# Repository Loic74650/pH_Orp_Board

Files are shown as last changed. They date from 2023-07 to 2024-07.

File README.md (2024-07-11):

# pH_Orp_Board
## A 16 bits, two-channels, analog to digital convertion board with galavnic isolation to measure pH and Orp levels in pools and similar environments

This project is based on the original project from Roberto Buti: https://github.com/reef-pi/pH-Board.<br />
This modified version features a double input for simultaneous pH and Orp measurements on the same board, based on the ADS1115 IC.<br />
This board is an ideal companion to the PoolMaster project: https://github.com/Loic74650/PoolMaster.<br />
The 5Volts power supply to this board should be low noise and low drift (sorry no spec).<br /><br />
A alternative (and likely better) routing of the board was performed by @Gixy31 and is available here: https://github.com/Gixy31/ESP32-PoolMaster/tree/main/pH_Orp%20Board%20V2

<br />
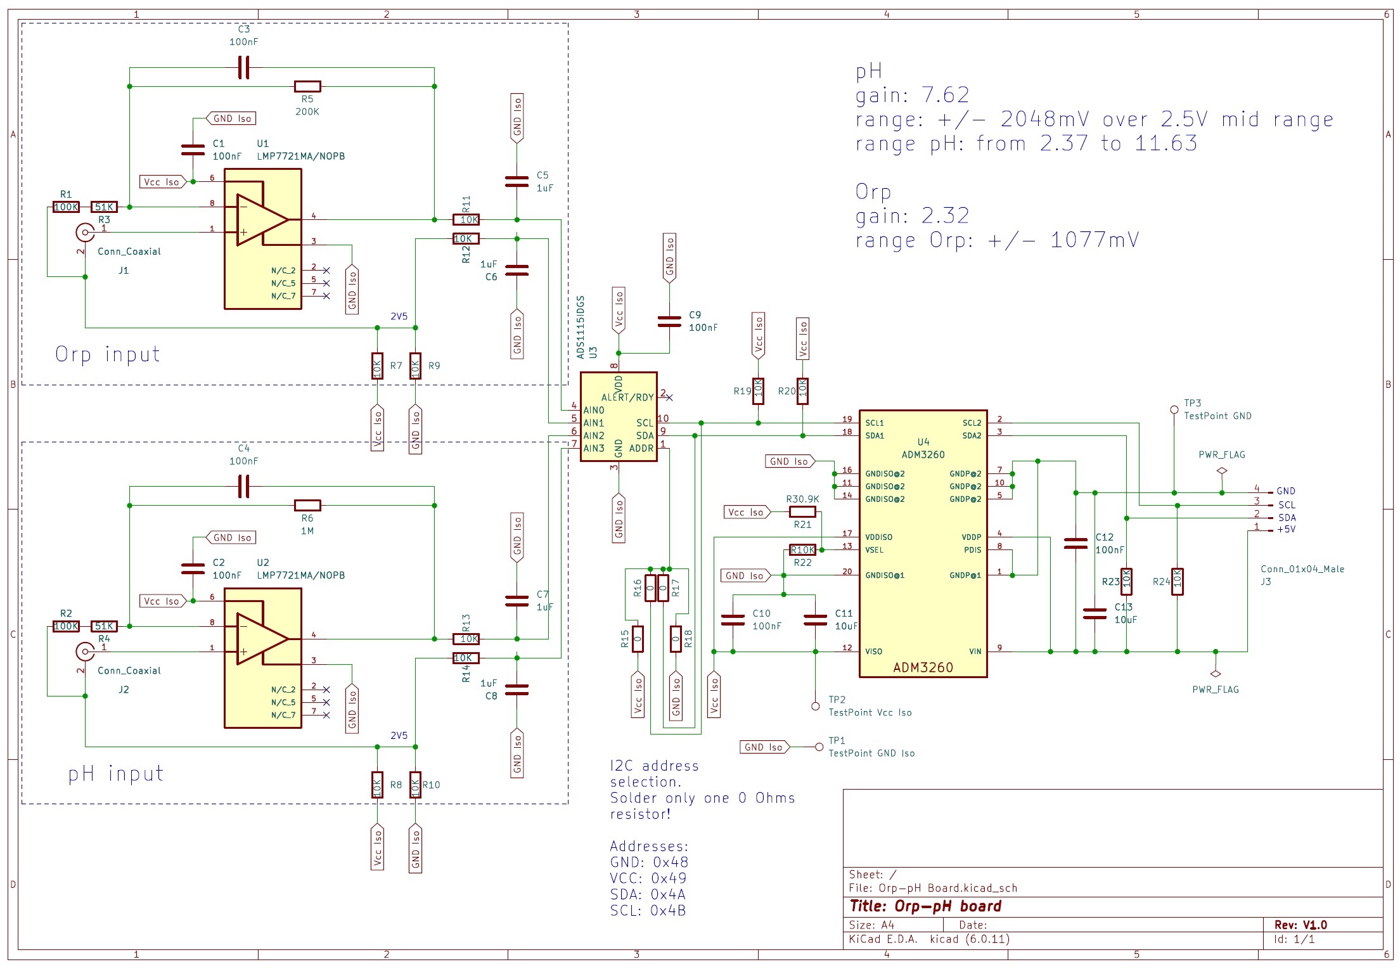
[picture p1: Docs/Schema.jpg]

Schematics <br /><br />

<br />
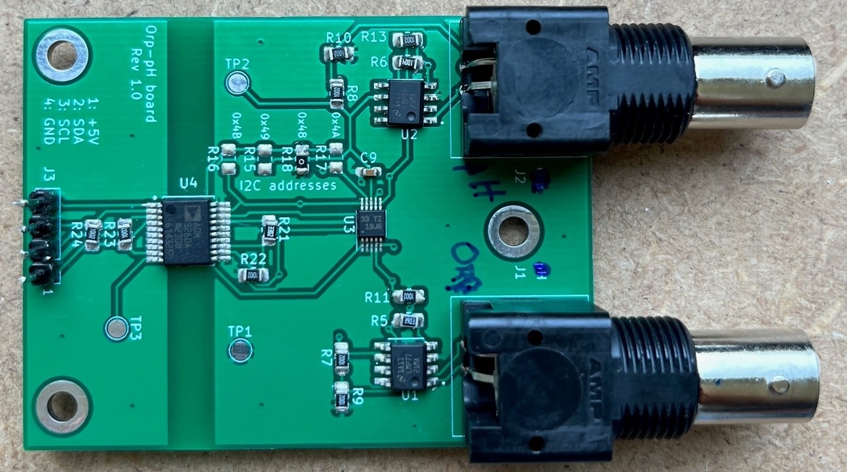
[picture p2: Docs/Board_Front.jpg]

PCB front <br /><br />

<br />
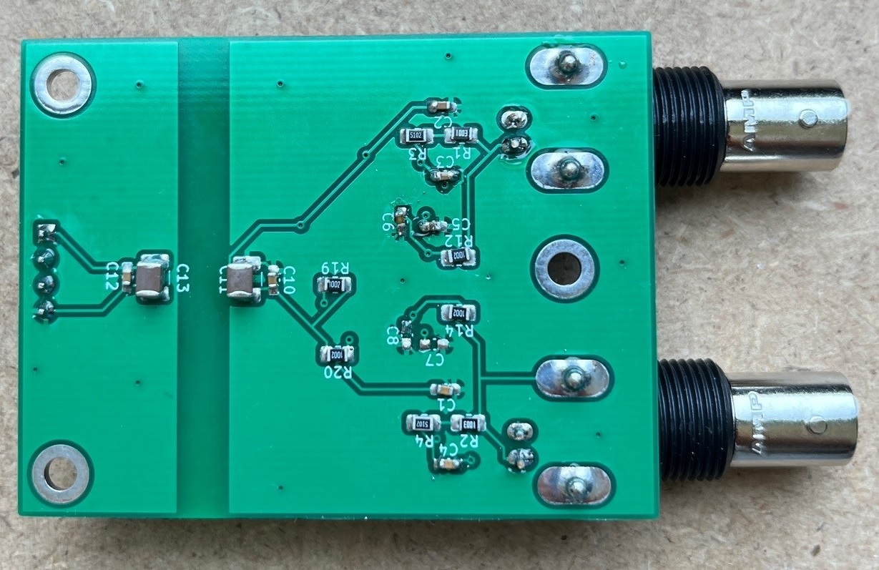
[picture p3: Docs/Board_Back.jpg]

PCB back <br /><br />

<br />
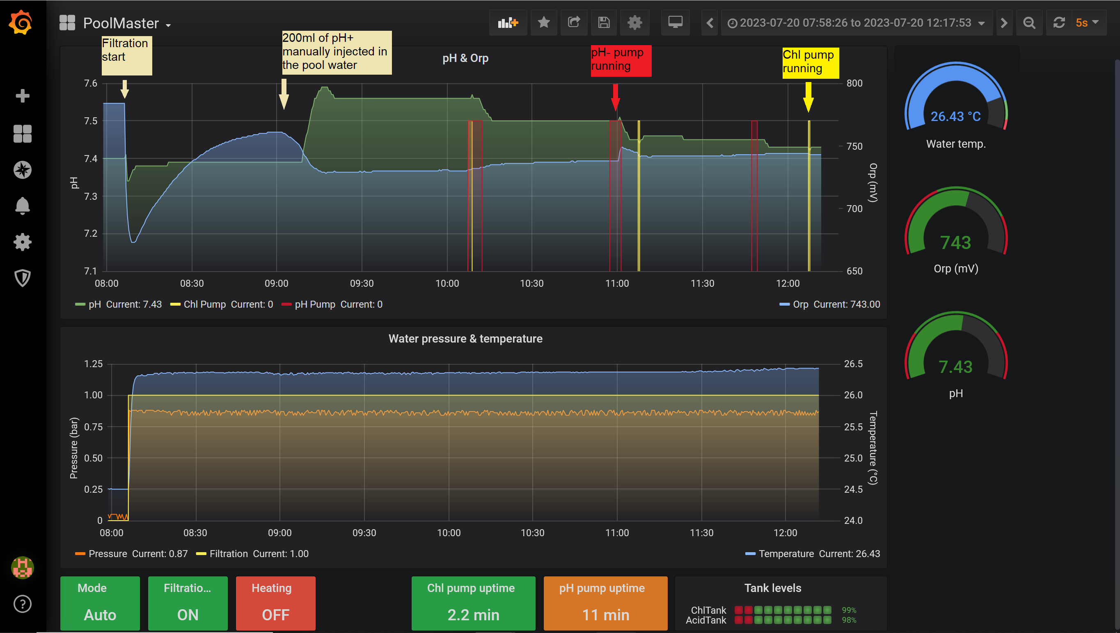
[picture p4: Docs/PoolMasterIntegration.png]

PoolMaster dashboard with pH_Orp_Board integrated<br /><br />

<br />
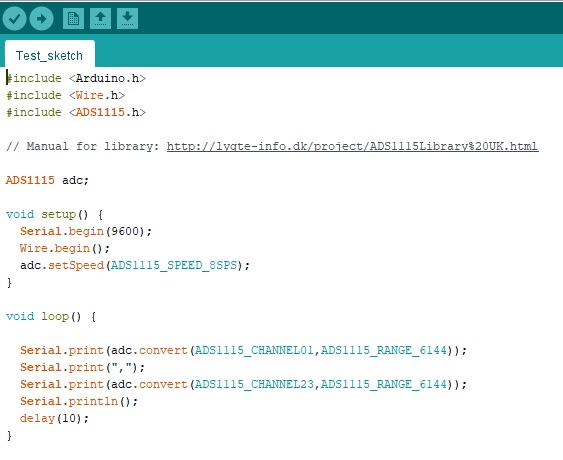
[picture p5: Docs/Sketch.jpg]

Basic sketch provided in this repository to test the PCB with this library: <br /><br />
https://lygte-info.dk/project/ADS1115Library%20UK.html<br /><br />

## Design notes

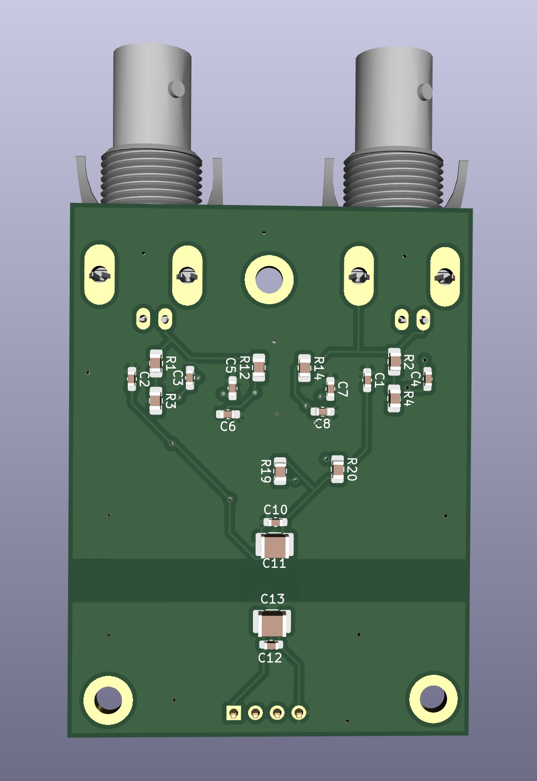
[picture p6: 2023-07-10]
Docs/PCB_Bottom.jpg

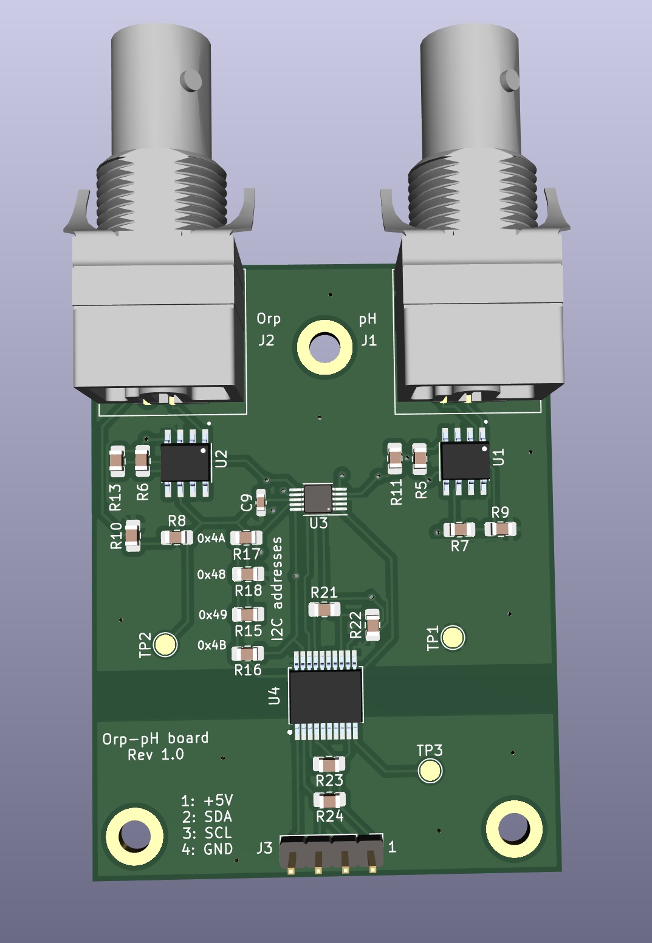
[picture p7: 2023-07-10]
Docs/PCB_Top.jpg

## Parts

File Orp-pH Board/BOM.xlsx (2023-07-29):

Column1 | Column2 | Column3 | Column4 | Column5 | Column6 | Column7 | Column8 | Column9
Source: | C:\Users\USER\Documents\GitHub\pH-Board\Kicad\Orp-pH Board\Orp-pH Board.kicad_sch
Date: | 25/05/2023 13:23:16
Tool: | Eeschema (6.0.11)
Generator: | C:\Program Files\KiCad\6.0\bin\scripting\plugins/bom_csv_grouped_by_value_with_fp.py
Component Count: | 47
Ref | Qnty | Value | Cmp name | Footprint | Description | Vendor | Unit Price HT€ | Total Price HT€
C1, C2, C3, C4, C9, C10, C12, | 7 | 100nF | C | Capacitor_SMD:C_0603_1608Metric_Pad1.08x0.95mm_HandSolder | Unpolarized capacitor |  |  | 0
C5, C6, C7, C8, | 4 | 1uF | C | Capacitor_SMD:C_0603_1608Metric_Pad1.08x0.95mm_HandSolder | Unpolarized capacitor |  |  | 0
C11, C13, | 2 | 10uF | C | Capacitor_SMD:C_1210_3225Metric_Pad1.33x2.70mm_HandSolder | Unpolarized capacitor |  |  | 0
J1, J2, | 2 | Conn_Coaxial | Conn_Coaxial | Connector_Coaxial:BNC_Amphenol_B6252HB-NPP3G-50_Horizontal | coaxial connector (BNC, SMA, SMB, SMC, Cinch/RCA, LEMO, ...) | https://www.mouser.fr/ProductDetail/TE-Connectivity-AMP/227161-9?qs=ZKw1f99oBB2J9LYPbCoP6Q%3D%3D | 6.06 | 12.12
J3, | 1 | Conn_01x04_Male | Conn_01x04_Male | Connector_PinHeader_2.54mm:PinHeader_1x04_P2.54mm_Vertical | Generic connector, single row, 01x04, script generated (kicad-library-utils/schlib/autogen/connector/) |  |  | 0
R1, R2, | 2 | 100K | R | Capacitor_SMD:C_0805_2012Metric_Pad1.18x1.45mm_HandSolder | Resistor |  |  | 0
R3, R4, | 2 | 51K | R | Capacitor_SMD:C_0805_2012Metric_Pad1.18x1.45mm_HandSolder | Resistor |  |  | 0
R5, | 1 | 200K | R | Capacitor_SMD:C_0805_2012Metric_Pad1.18x1.45mm_HandSolder | Resistor |  |  | 0
R6, | 1 | 1M | R | Capacitor_SMD:C_0805_2012Metric_Pad1.18x1.45mm_HandSolder | Resistor |  |  | 0
R7, R8, R9, R10, R11, R12, R13, R14, R19, R20, R23, R24, | 12 | 10K | R | Capacitor_SMD:C_0805_2012Metric_Pad1.18x1.45mm_HandSolder | Resistor |  |  | 0
R15, R16, R17, R18, | 4 | 0 | R | Capacitor_SMD:C_0805_2012Metric_Pad1.18x1.45mm_HandSolder | Resistor |  |  | 0
R21, | 1 | R30.9K | R | Capacitor_SMD:C_0805_2012Metric_Pad1.18x1.45mm_HandSolder | Resistor |  |  | 0
R22, | 1 | R10K | R | Capacitor_SMD:C_0805_2012Metric_Pad1.18x1.45mm_HandSolder | Resistor |  |  | 0
TP1, | 1 | TestPoint GND Iso | TestPoint | TestPoint:TestPoint_Pad_D2.0mm | test point |  |  | 0
TP2, | 1 | TestPoint Vcc Iso | TestPoint | TestPoint:TestPoint_Pad_D2.0mm | test point |  |  | 0
TP3, | 1 | TestPoint Vcc | TestPoint | TestPoint:TestPoint_Pad_D2.0mm | test point |  |  | 0
U1, U2, | 2 | LMP7721MA/NOPB | LMP7721MA{slash}NOPB | SOIC127P599X175-8N |  | https://www.ti.com/lit/ds/symlink/ads1115-q1.pdf?HQS=dis-mous-null-mousermode-dsf-pf-null-wwe&ts=1685176951071 | 5.68 | 11.36
U3, | 1 | ADS1115IDGS | ADS1115IDGS | Package_SO:TSSOP-10_3x3mm_P0.5mm | Ultra-Small, Low-Power, I2C-Compatible, 860-SPS, 16-Bit ADCs With Internal Reference, Oscillator, and Programmable Comparator, VSSOP-10 |  | 6.26 | 6.26
U4, | 1 | ADM3260 | ADM3260 | ADM3260:SOP65P780X200-20N |  |  | 10.2 | 10.2
 |  |  |  |  |  |  | TOTAL HT€ | 39.94

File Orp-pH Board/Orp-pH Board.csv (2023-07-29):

Source: | C:\Users\USER\Documents\GitHub\pH-Board\Kicad\Orp-pH Board\Orp-pH Board.kicad_sch
Date: | 25/05/2023 13:23:16
Tool: | Eeschema (6.0.11)
Generator: | C:\Program Files\KiCad\6.0\bin\scripting\plugins/bom_csv_grouped_by_value_with_fp.py
Component Count: | 47
Ref | Qnty | Value | Cmp name | Footprint | Description | Vendor
C1, C2, C3, C4, C9, C10, C12, | 7 | 100nF | C | Capacitor_SMD:C_0603_1608Metric_Pad1.08x0.95mm_HandSolder | Unpolarized capacitor
C5, C6, C7, C8, | 4 | 1uF | C | Capacitor_SMD:C_0603_1608Metric_Pad1.08x0.95mm_HandSolder | Unpolarized capacitor
C11, C13, | 2 | 10uF | C | Capacitor_SMD:C_1210_3225Metric_Pad1.33x2.70mm_HandSolder | Unpolarized capacitor
J1, J2, | 2 | Conn_Coaxial | Conn_Coaxial | Connector_Coaxial:BNC_Amphenol_B6252HB-NPP3G-50_Horizontal | coaxial connector (BNC, SMA, SMB, SMC, Cinch/RCA, LEMO, ...)
J3, | 1 | Conn_01x04_Male | Conn_01x04_Male | Connector_PinHeader_2.54mm:PinHeader_1x04_P2.54mm_Vertical | Generic connector, single row, 01x04, script generated (kicad-library-utils/schlib/autogen/connector/)
R1, R2, | 2 | 100K | R | Capacitor_SMD:C_0805_2012Metric_Pad1.18x1.45mm_HandSolder | Resistor
R3, R4, | 2 | 51K | R | Capacitor_SMD:C_0805_2012Metric_Pad1.18x1.45mm_HandSolder | Resistor
R5, | 1 | 200K | R | Capacitor_SMD:C_0805_2012Metric_Pad1.18x1.45mm_HandSolder | Resistor
R6, | 1 | 1M | R | Capacitor_SMD:C_0805_2012Metric_Pad1.18x1.45mm_HandSolder | Resistor
R7, R8, R9, R10, R11, R12, R13, R14, R19, R20, R23, R24, | 12 | 10K | R | Capacitor_SMD:C_0805_2012Metric_Pad1.18x1.45mm_HandSolder | Resistor
R15, R16, R17, R18, | 4 | 0 | R | Capacitor_SMD:C_0805_2012Metric_Pad1.18x1.45mm_HandSolder | Resistor
R21, | 1 | R30.9K | R | Capacitor_SMD:C_0805_2012Metric_Pad1.18x1.45mm_HandSolder | Resistor
R22, | 1 | R10K | R | Capacitor_SMD:C_0805_2012Metric_Pad1.18x1.45mm_HandSolder | Resistor
TP1, | 1 | TestPoint GND Iso | TestPoint | TestPoint:TestPoint_Pad_D2.0mm | test point
TP2, | 1 | TestPoint Vcc Iso | TestPoint | TestPoint:TestPoint_Pad_D2.0mm | test point
TP3, | 1 | TestPoint Vcc | TestPoint | TestPoint:TestPoint_Pad_D2.0mm | test point
U1, U2, | 2 | LMP7721MA/NOPB | LMP7721MA{slash}NOPB | SOIC127P599X175-8N
U3, | 1 | ADS1115IDGS | ADS1115IDGS | Package_SO:TSSOP-10_3x3mm_P0.5mm | Ultra-Small, Low-Power, I2C-Compatible, 860-SPS, 16-Bit ADCs With Internal Reference, Oscillator, and Programmable Comparator, VSSOP-10
U4, | 1 | ADM3260 | ADM3260 | ADM3260:SOP65P780X200-20N

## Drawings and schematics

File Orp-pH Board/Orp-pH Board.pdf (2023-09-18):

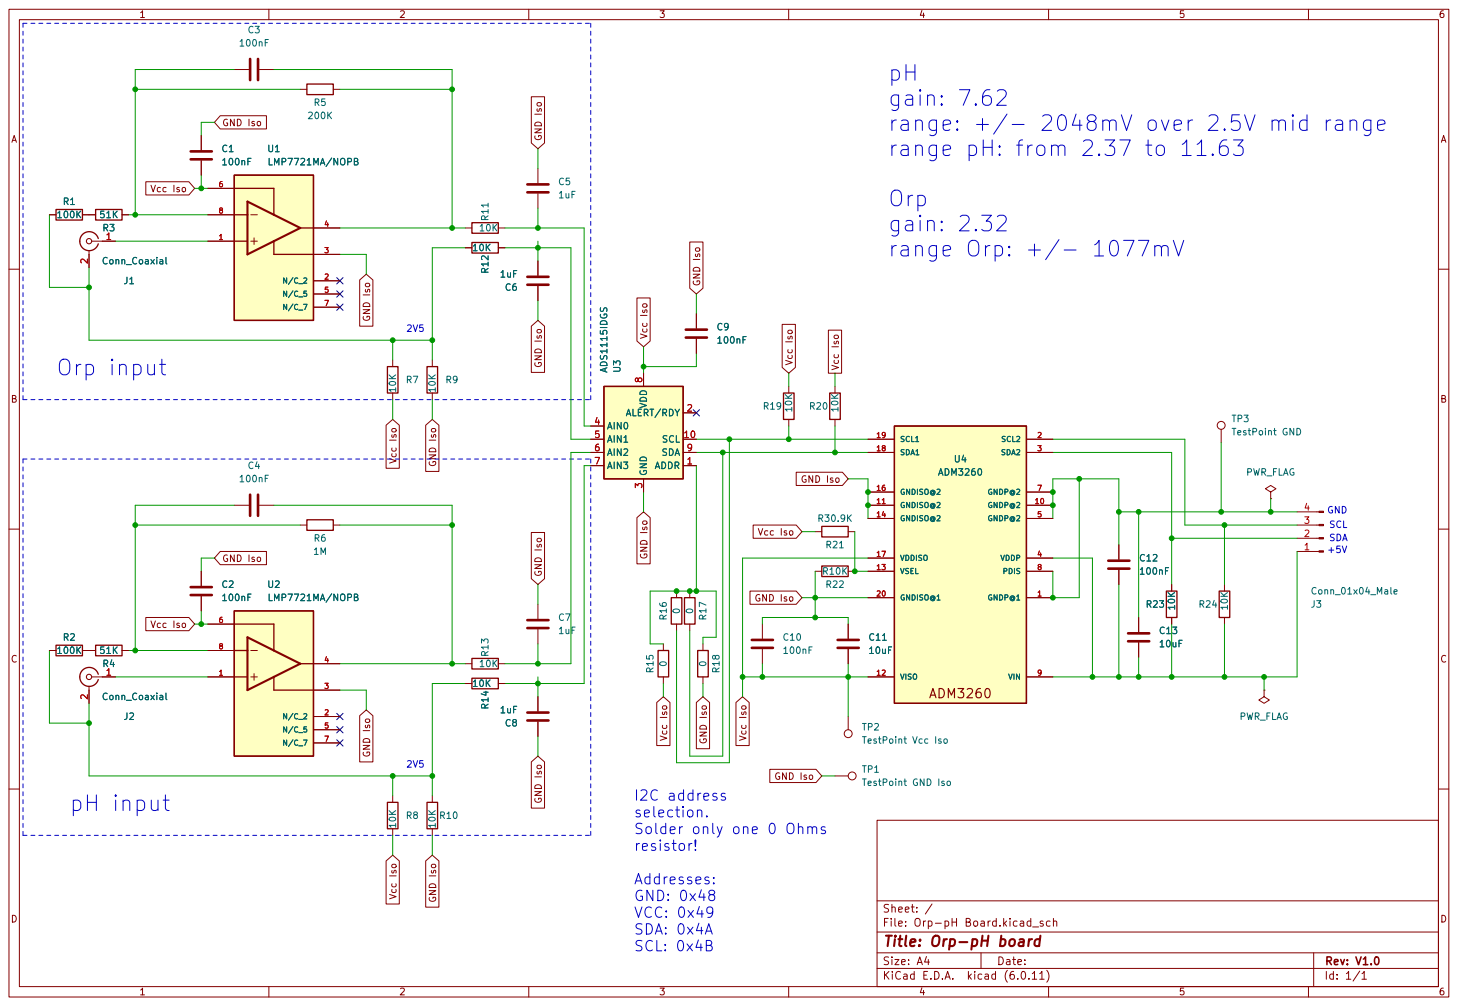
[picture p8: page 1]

gain: 7.62
range pH: from 2.37 to 11.63

selection.
Solder only one 0 Ohms
resistor!

Id: 1/1 Title: Orp-pH board

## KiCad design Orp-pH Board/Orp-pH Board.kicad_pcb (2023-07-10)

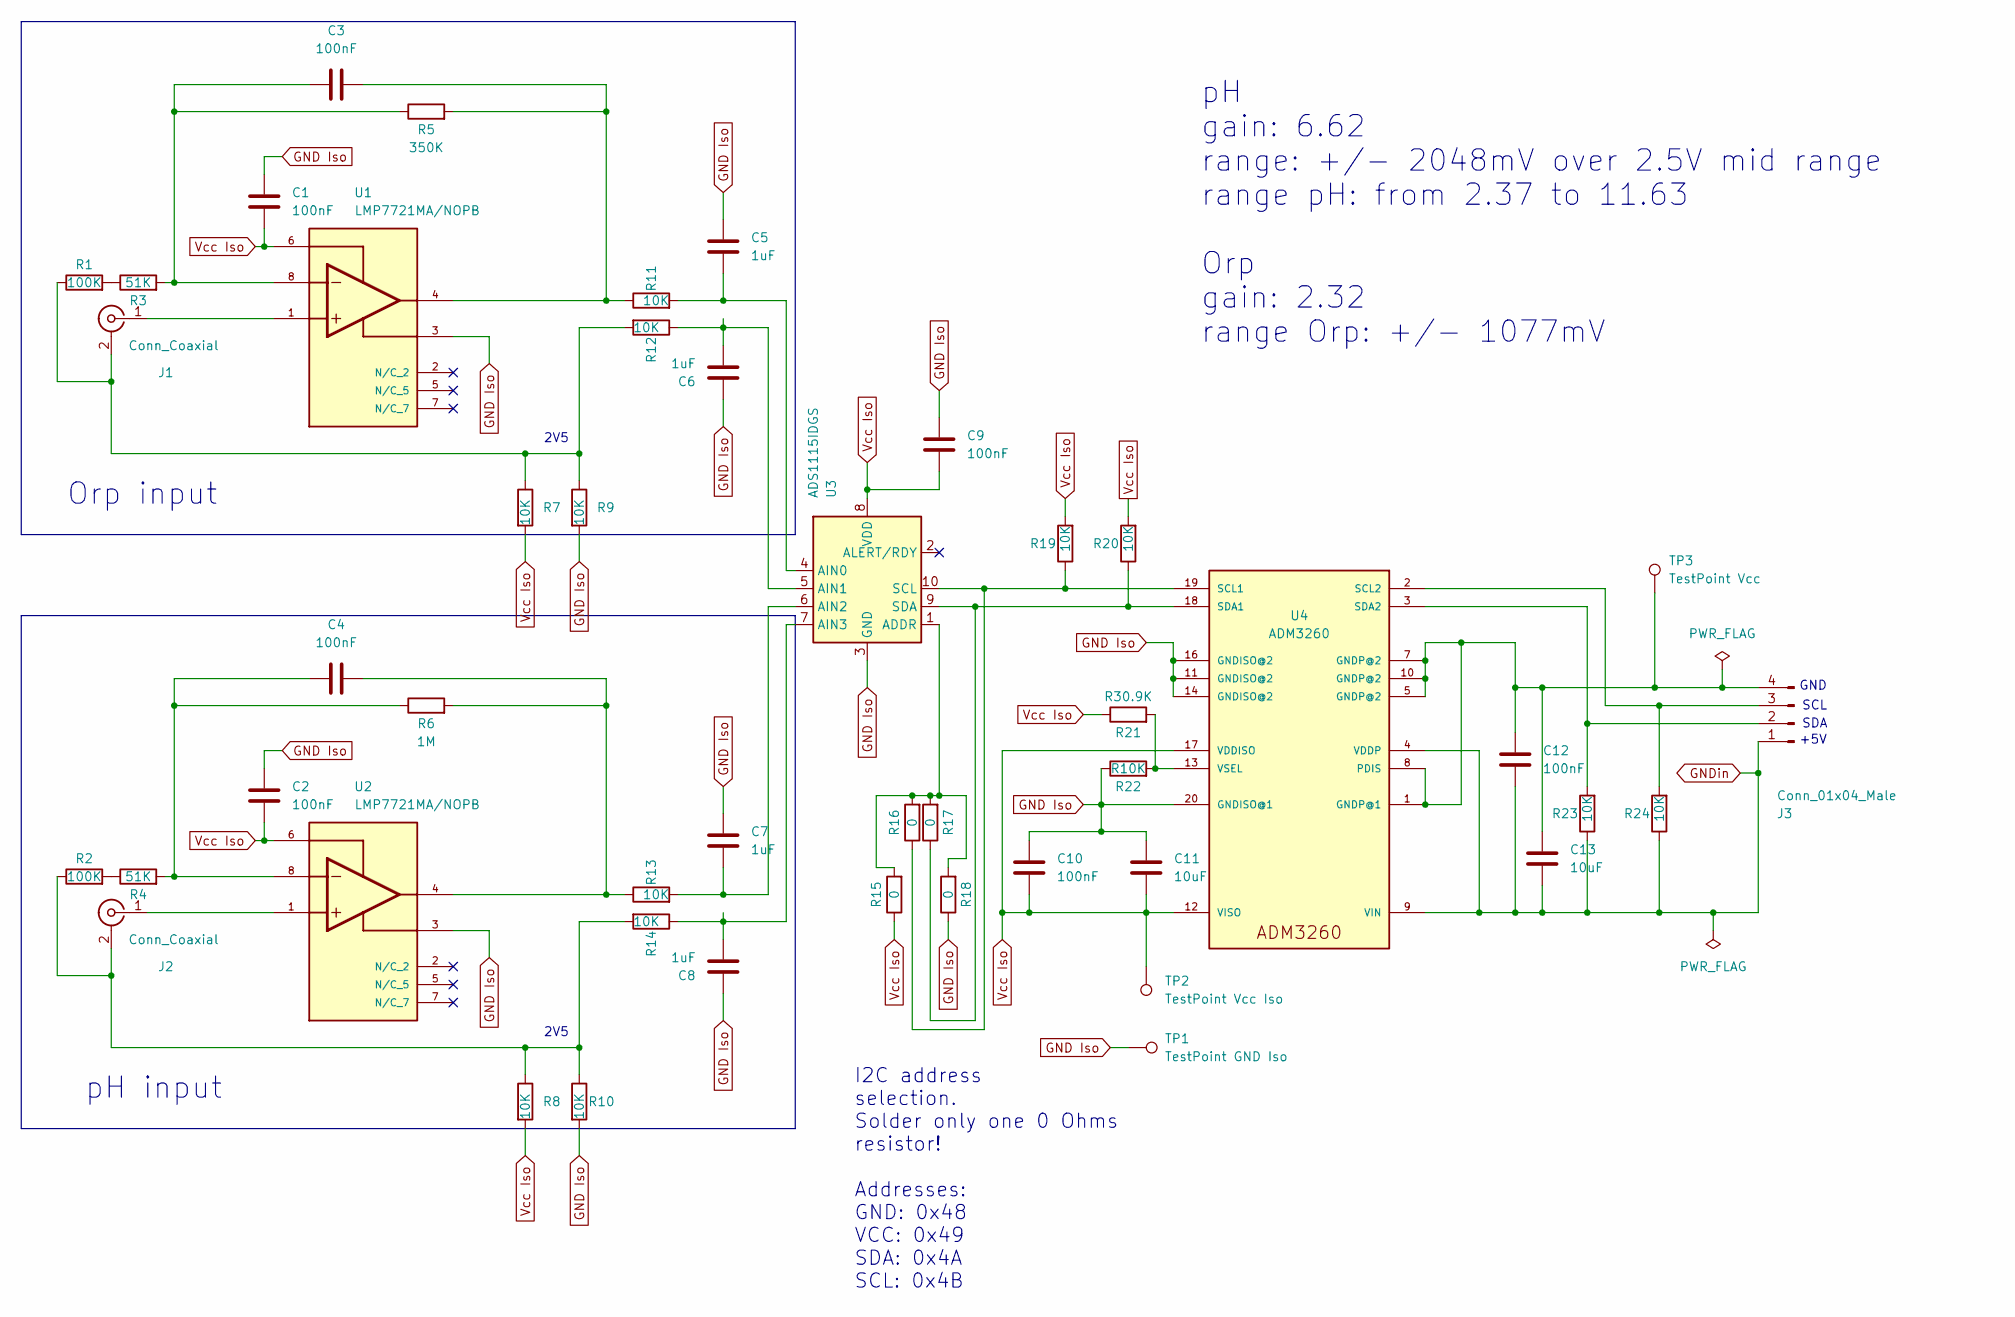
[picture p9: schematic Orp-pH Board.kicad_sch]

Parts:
C1, C2, C3, C4, C9, C10, C12: 100nF; C_0603_1608Metric_Pad1.08x0.95mm_HandSolder
C5, C6, C7, C8: 1uF; C_0603_1608Metric_Pad1.08x0.95mm_HandSolder
C11, C13: 10uF; C_1210_3225Metric_Pad1.33x2.70mm_HandSolder
J1, J2: Conn_Coaxial; BNC_Amphenol_B6252HB-NPP3G-50_Horizontal
J3: Conn_01x04_Male; PinHeader_1x04_P2.54mm_Vertical
R1, R2: 100K; C_0805_2012Metric_Pad1.18x1.45mm_HandSolder
R3, R4: 51K; C_0805_2012Metric_Pad1.18x1.45mm_HandSolder
R5: 350K; C_0805_2012Metric_Pad1.18x1.45mm_HandSolder
R6: 1M; C_0805_2012Metric_Pad1.18x1.45mm_HandSolder
R7, R8, R9, R10, R11, R12, R13, R14, R19, R20, R23, R24: 10K; C_0805_2012Metric_Pad1.18x1.45mm_HandSolder
R15, R16, R17, R18: 0; C_0805_2012Metric_Pad1.18x1.45mm_HandSolder
R21: R30.9K; C_0805_2012Metric_Pad1.18x1.45mm_HandSolder
R22: R10K; C_0805_2012Metric_Pad1.18x1.45mm_HandSolder
TP1: TestPoint GND Iso; TestPoint_Pad_D2.0mm
TP2: TestPoint Vcc Iso; TestPoint_Pad_D2.0mm
TP3: TestPoint Vcc; TestPoint_Pad_D2.0mm
U1, U2: LMP7721MA/NOPB; SOIC127P599X175-8N; PARTREV E
U3: ADS1115IDGS; VSSOP-10_3x3mm_P0.5mm
U4: ADM3260; SOP65P780X200-20N

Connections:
GND Iso: C1.1, C2.1, C5.1, C6.1, C7.1, C8.1, C9.1, C10.1, C11.1, R9.2, R10.2, R18.1, R22.1, TP1.1, U1.3, U2.3, U3.3 (GND), U4.11 (GNDISO@2), U4.14 (GNDISO@2), U4.16 (GNDISO@2), U4.20 (GNDISO@1)
unnamed: C3.1, R3.2, R5.1, U1.8
unnamed: C3.2, R5.2, R11.1, U1.4
unnamed: C4.1, R4.2, R6.1, U2.8
unnamed: C4.2, R6.2, R13.1, U2.4
unnamed: C5.2, R11.2, U3.4 (AIN0)
unnamed: C6.2, R12.1, U3.5 (AIN1)
unnamed: C7.2, R13.2, U3.6 (AIN2)
unnamed: C8.2, R14.1, U3.7 (AIN3)
unnamed: C12.2, C13.2, J3.1, R23.1, R24.1, U4.4 (VDDP), U4.9 (VIN)
unnamed: J1.1 (In), U1.1
unnamed: J1.2 (Ext), R1.1, R7.1, R9.1, R12.2
unnamed: J2.1 (In), U2.1
unnamed: J2.2 (Ext), R2.1, R8.1, R10.1, R14.2
unnamed: J3.2, R23.2, U4.3 (SDA2)
unnamed: J3.3, R24.2, U4.2 (SCL2)
unnamed: R1.2, R3.1
unnamed: R2.2, R4.1
unnamed: R15.2, R16.2, R17.2, R18.2, U3.1 (ADDR)
unnamed: R16.1, R19.1, U3.10 (SCL), U4.19 (SCL1)
unnamed: R17.1, R20.1, U3.9 (SDA), U4.18 (SDA1)
unnamed: R21.2, R22.2, U4.13 (VSEL)
Vcc Iso: C1.2, C2.2, C9.2, C10.2, C11.2, R7.2, R8.2, R15.1, R19.2, R20.2, R21.1, TP2.1, U1.6, U2.6, U3.8 (VDD), U4.12 (VISO), U4.17 (VDDISO)

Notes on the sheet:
+5V
GND
Orp input
SDA
I2C address selection. Solder only one 0 Ohms resistor! Addresses: GND: 0x48 VCC: 0x49 SDA: 0x4A SCL: 0x4B
SCL
2V5
pH input
pH gain: 6.62 range: +/- 2048mV over 2.5V mid range range pH: from 2.37 to 11.63 Orp gain: 2.32 range Orp: +/- 1077mV

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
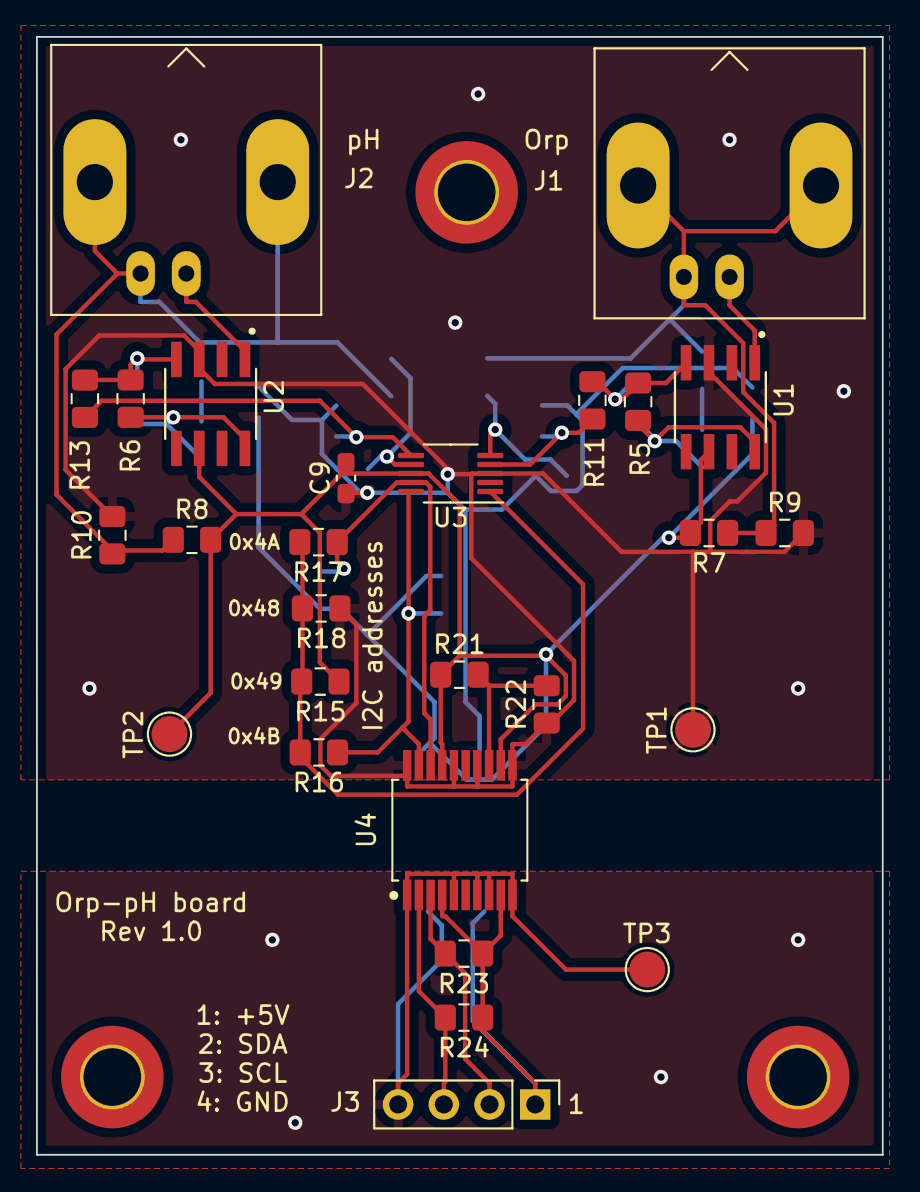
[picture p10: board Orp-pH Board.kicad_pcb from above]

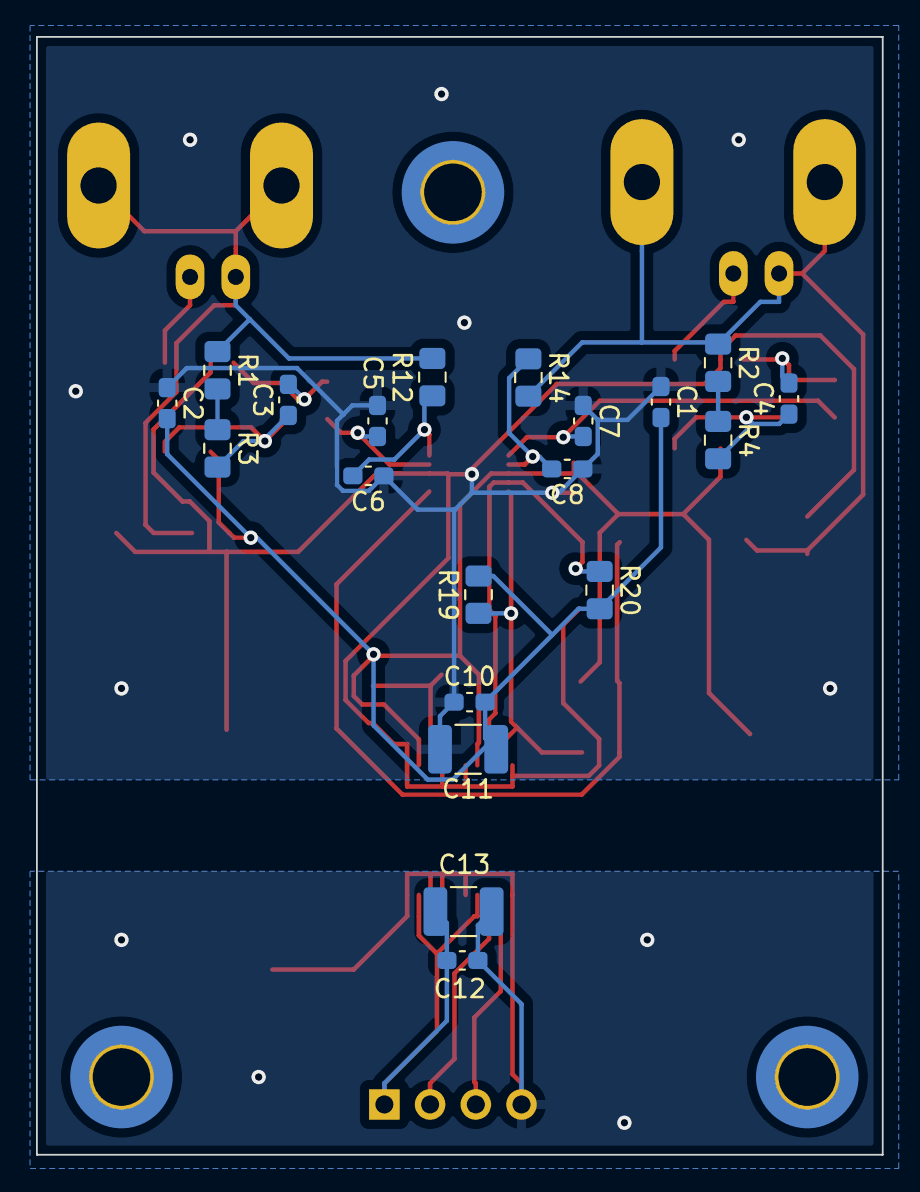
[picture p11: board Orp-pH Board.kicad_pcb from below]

Board: 2 copper layers, 47.0 x 62.1 mm, 50 parts (20 on the bottom side), 24 nets.

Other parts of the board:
REF1, REF2, REF3: MountingHole_3.2mm_M3_ISO7380_Pad_TopBottom

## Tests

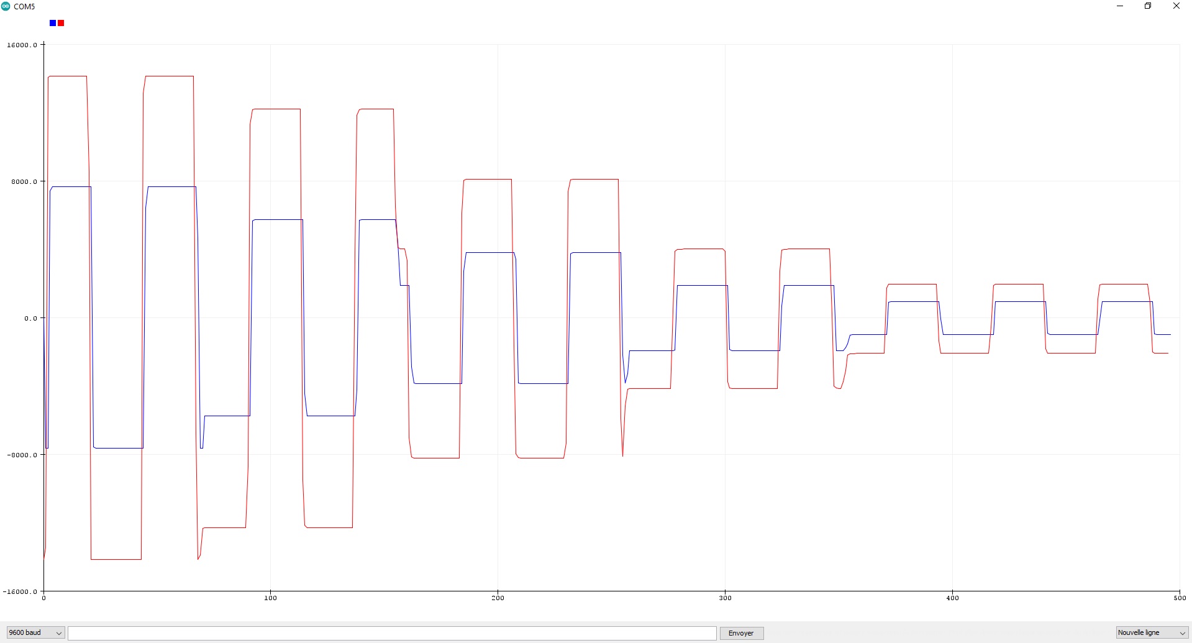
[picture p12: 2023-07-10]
Docs/ADC_Test_pH_Board.jpg

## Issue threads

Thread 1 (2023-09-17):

pH gain value

Gixy31, 2023-09-17:
Hello Loïc,
The gain of the pH AOP is 7.62 and not 6.62 as mentionned on the schematic : 1+1M/151k = 7.62
Best regards
Denis

Loic74650, 2023-09-18:
Thank you Denis, fixed.

Closed 2023-09-18.

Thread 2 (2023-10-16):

Power consumption of the board

Silverspur, 2023-10-16:
Hi Loïc,
I'm looking for an estimate of the board max power consumption to find a suitable voltage regulator to power it. Could you provide any information about that?
In any case, thanks a lot for the design!

Loic74650, 2023-10-16:
Greetings

I have not measured it but the max. consumption should be in the ADM3260 spreadsheet (https://github.com/Loic74650/pH_Orp_Board/blob/main/Datasheets/ADM3260.pdf)

I think it should be a few 100mA max

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

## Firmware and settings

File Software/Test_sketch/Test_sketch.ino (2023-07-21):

#include <Arduino.h>
#include <Wire.h>
#include <ADS1115.h>

// Manual for library: http://lygte-info.dk/project/ADS1115Library%20UK.html

ADS1115 adc;

void setup() {
  Serial.begin(9600);
  Wire.begin();
  adc.setSpeed(ADS1115_SPEED_8SPS);
}

void loop() {

  Serial.print(adc.convert(ADS1115_CHANNEL01,ADS1115_RANGE_6144));
  //Serial.print(",");
  //Serial.print(adc.convert(ADS1115_CHANNEL23,ADS1115_RANGE_6144));
  Serial.println();
  delay(10);
}

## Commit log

2023-07-29 update value of R5 resistor
    [BOM.xlsx, Orp-pH Board.csv]
2023-08-25 fixed small errors on the schema
    [Orp-pH Board.kicad_sch]
2023-09-18 fixed gain error in label of schematics
    [Orp-pH Board.kicad_sch]
